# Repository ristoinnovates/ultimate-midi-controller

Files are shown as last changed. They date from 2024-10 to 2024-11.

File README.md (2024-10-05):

# Ultimate MIDI Controller

Ultimate MIDI Controller

## Overview

The Ultimate MIDI Controller is designed to function as both a MIDI keyboard and an effects controller. Whether you're a music producer or live performer, this controller provides seamless control over MIDI devices and software.

🎬 **Watch the build process on YouTube: [Ultimate MIDI Controller Build](https://www.youtube.com/watch?v=xiZ_aWyoJGo)**

## Features

- **8 Programmable Pushbuttons**: Fully customizable to control your MIDI software or devices.
- **2 Sliding Potentiometers (10K)**: Smooth control for faders or other continuous parameters.
- **2 Rotary Potentiometers (10K)**: Perfect for volume, effects, or other rotary controls.
- **1 Rotary Encoder with Button**: Precision control for effects, menus, or settings.
- **1 Joystick**: Adds dynamic control, ideal for pitch bending, modulation, or any custom input.
- **30 Mechanical Key Switches**: Custom tactile and clicky switches with keycaps, offering a responsive feel.
- **Tiny Neodymium Magnets**: Secure and modular connections for various components.
- **Display (SPI Protocol)**: Provides real-time feedback on settings, effects, or controls.
- **Custom 3D Printed Enclosure**: Designed from scratch, this custom top and bottom enclosure houses all components securely.
- **Powered by Arduino Pro Micro**: The heart of the controller, driving all the components with powerful control.

## Components

- **Potentiometers**: 10K ohm (linear)
- **Switches**: Clicky mechanical switches with keycaps
- **Display**: SPI-connected display
- **3D Printed Enclosure**: Custom-designed for a sleek, modular build

For a full list of components and assembly details, visit: [Ultimate MIDI Controller on RistoInnovates.com](https://ristoinnovates.com/product/ultimate-midi-controller/)

## Downloads

- **Enclosure STL Files**: Download the 3D-printable files for the top and bottom enclosure.
- **Schematics & Code**: Download the wiring schematics and Arduino code.

> **Note:** The code is actively being developed. If you find any missing features or bugs, check back later for updates.

## How to Build

1. Print the enclosure using the provided STL files.
2. Assemble the components as per the schematics.
3. Upload the provided Arduino code to your Pro Micro.
4. Enjoy your new customizable MIDI controller!

## Contributions

Feel free to submit pull requests or open issues if you have any ideas or improvements!

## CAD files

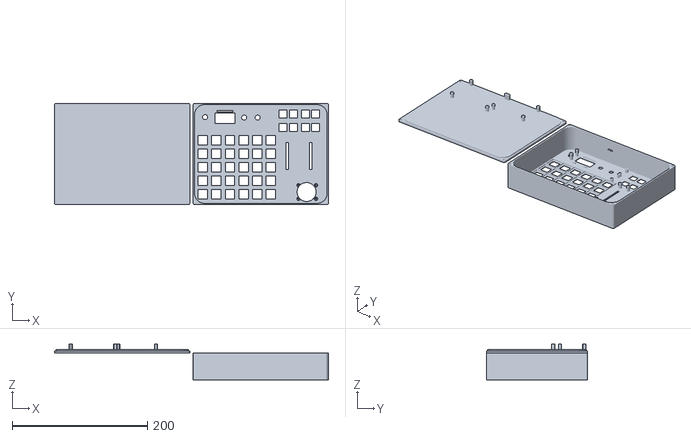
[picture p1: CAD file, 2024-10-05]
Ultimate Midi Controller.stl
405.0 x 150.0 x 53.0

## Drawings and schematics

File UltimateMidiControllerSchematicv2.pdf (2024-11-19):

1 | 2 U1.25
1 | 2 U1.25

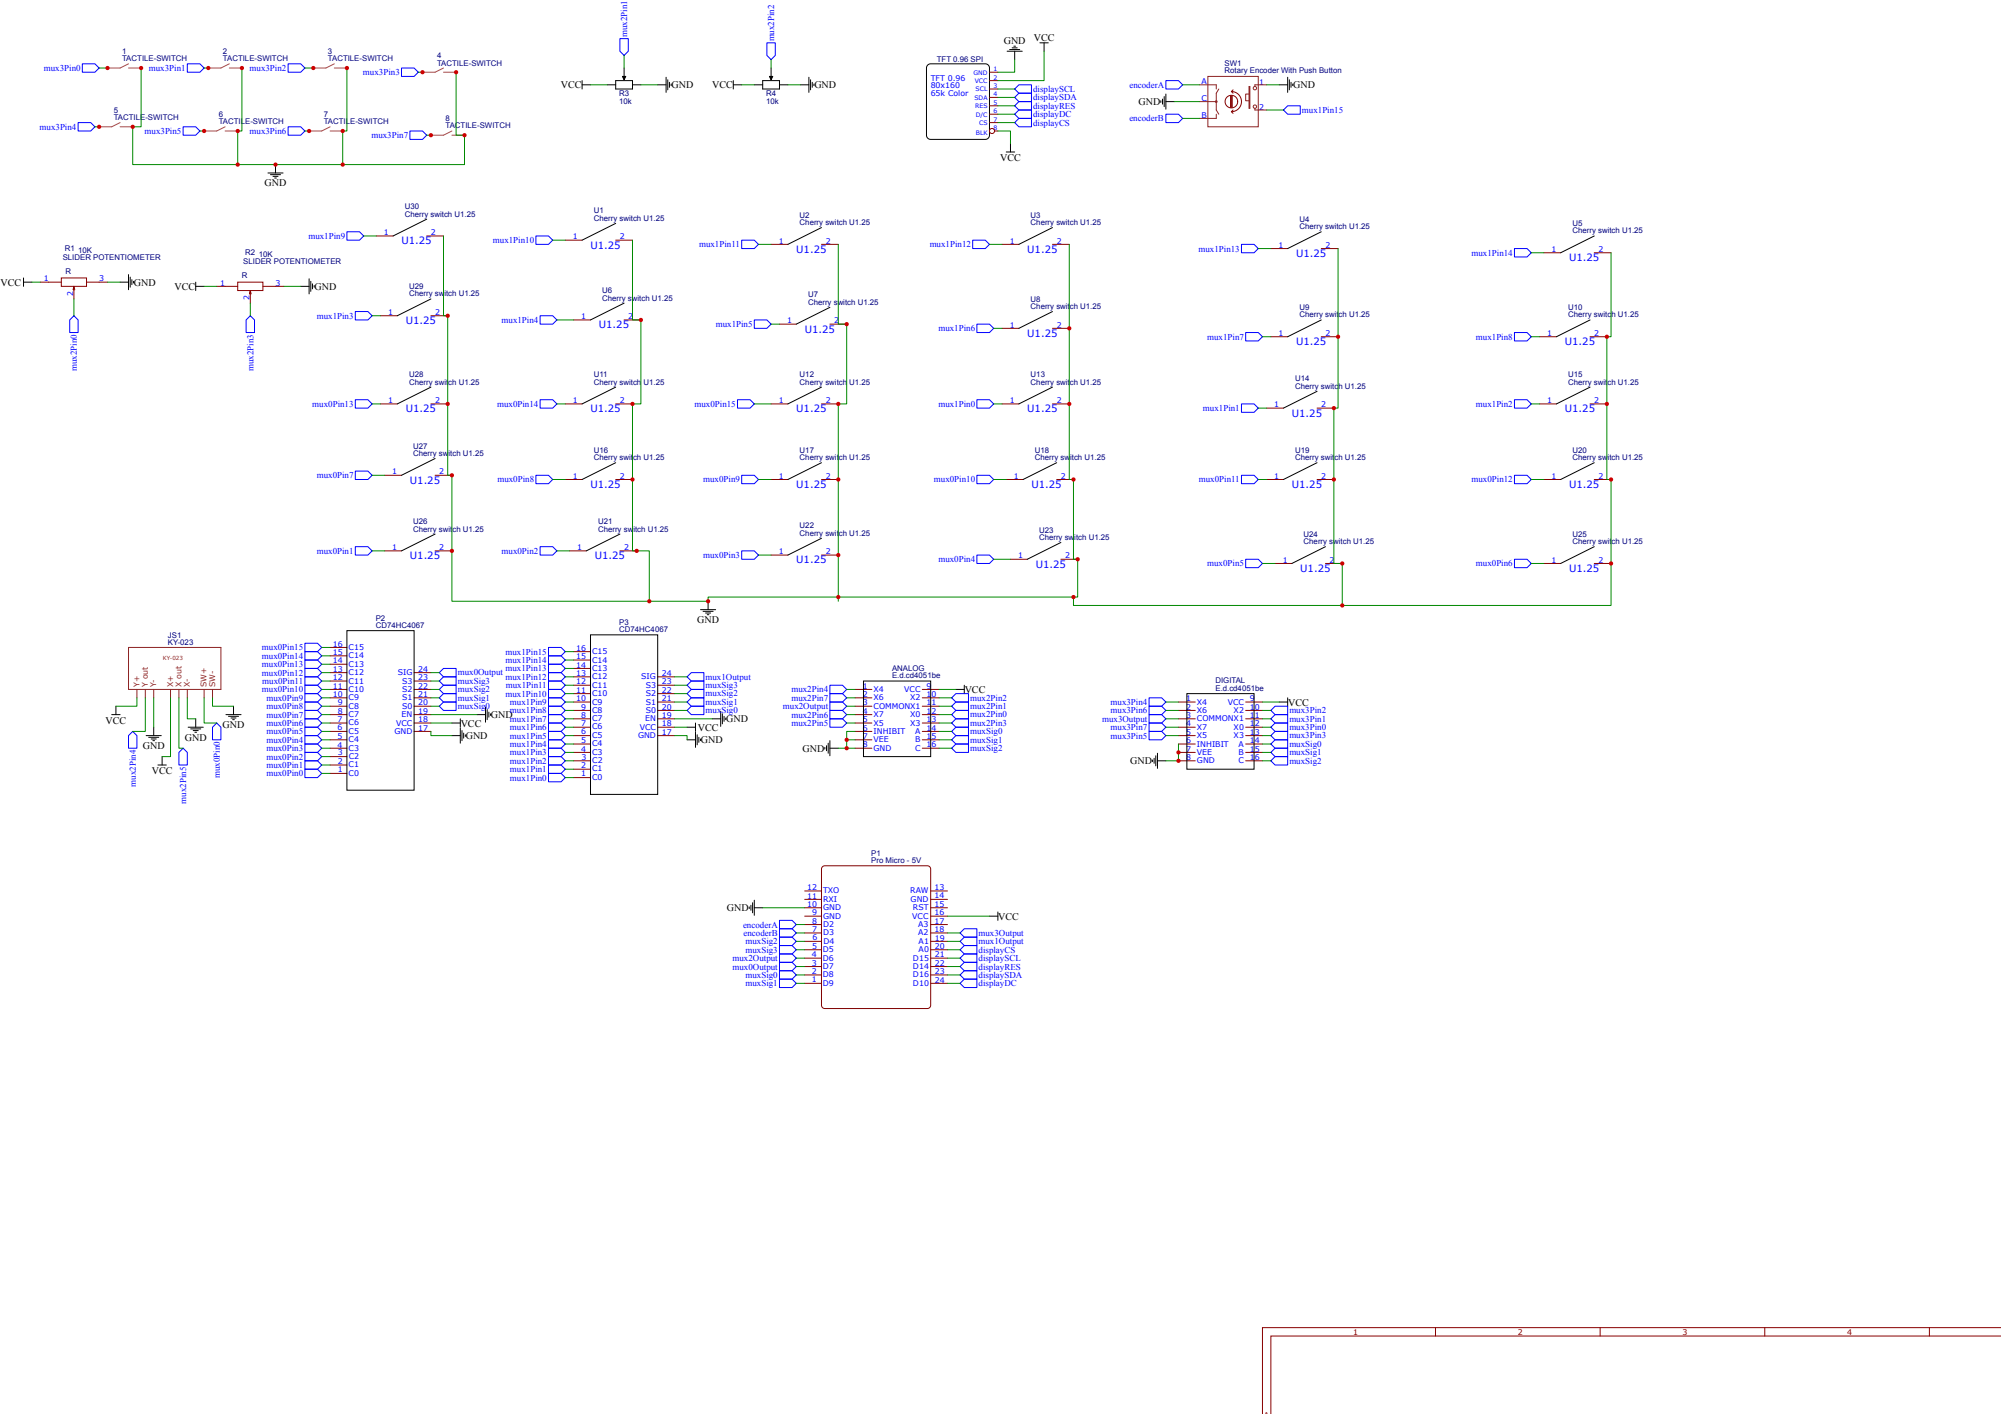
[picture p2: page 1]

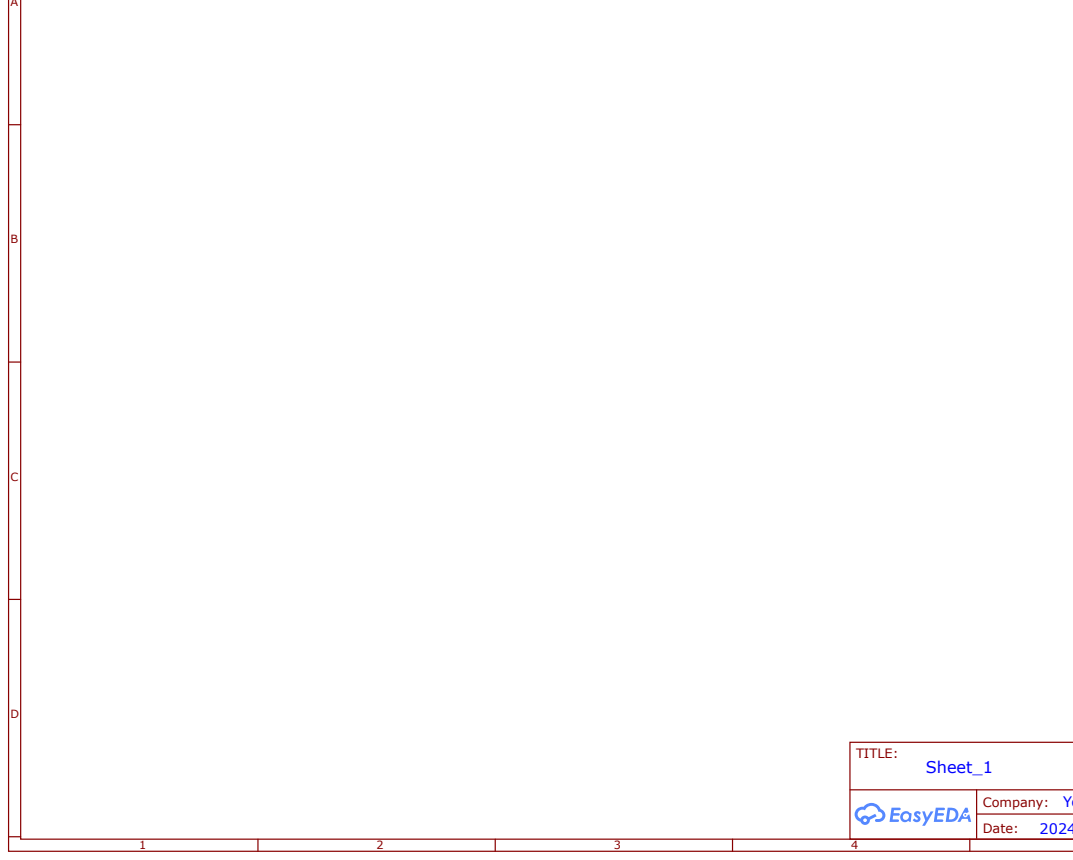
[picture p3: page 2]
TITLE:; Sheet_1; Date:; Company: Yo

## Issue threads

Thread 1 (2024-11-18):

mux2pin15

ragekillen, 2024-11-18:
Is the rotary encoder with button supposed to be mux1pin15 or is it supposed to go to pin 15 on the cd4051be chip (muxSig1). pretty sure its just a typo in the schematic

ristoinnovates, 2024-11-18:
You are correct! Good catch! It's supposed to be mux1Pin15.

I counted the 4067s as one and two, and the 4051s as one and two as well when making the schematic.

Thank you for checking it. I'll update it when I get a chance! Send me an email at ristoinnovates@gmail.com, I'll send you a 15% OFF coupon code if you ever want to get a device from my website.

Thanks!

ragekillen, 2024-11-18:
thanks for confirming that. As for the coupon i appreciate the offer but no need i would rather support you by paying the full amount

Closed 2024-11-18.

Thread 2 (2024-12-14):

couple questions / issues

ragekillen, 2024-12-14:
1. 7 keys are out of order in FL Studio is there any way to realign them in the code (serial output says there in the correct order)
2. is there any use to the FX Ctrl / mixer section at this time or is it just kind of there for now

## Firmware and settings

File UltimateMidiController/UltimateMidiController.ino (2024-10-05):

#include <Arduino.h>
#include "MIDIUSB.h"
#include <Encoder.h>
#include "Keyboard.h"
// Display Libraries
#include <Adafruit_GFX.h>    // Core graphics library
#include <Adafruit_ST7735.h> // Hardware-specific library for ST7735
#include <SPI.h>

// For the Adafruit 0.96" TFT with ST7735
#define TFT_CS     18  // Chip select line for TFT (can be any digital pin)
#define TFT_RST    14  // Reset line for TFT (or connect to Arduino RESET pin)
#define TFT_DC     10  // Data/command line for TFT (can be any digital pin)
#define TFT_MOSI   16  // Data out (MOSI) pin for SPI
#define TFT_SCLK   15  // Clock out (SCLK) pin for SPI

Adafruit_ST7735 tft = Adafruit_ST7735(TFT_CS, TFT_DC, TFT_RST);


// PINOUT
// MUX
// Outputs
int muxChannel1 = 8;
int muxChannel2 = 9;
int muxChannel3 = 4;
int muxChannel4 = 5;

// Inputs
int muxPotsInput = A7; // 8 channel analog
int muxSwitchesInput1 = 7; // 16 channel digital
int muxSwitchesInput2 = 19; // 16 channel digital
int muxPushButtonsInput = 20; // 8 channel digital


// # MULTIPLEXER 1 BUTTONS - 8 CH

const int NUMBER_MUX_1_BUTTONS = 8;
bool muxButtons1CurrentState[NUMBER_MUX_1_BUTTONS] = {0};
bool muxButtons1PreviousState[NUMBER_MUX_1_BUTTONS] = {0};

unsigned long lastDebounceTimeMUX1[NUMBER_MUX_1_BUTTONS] = {0};
unsigned long debounceDelayMUX1 = 5;

// # -------------------

// # MULTIPLEXER 2 BUTTONS - 16 CH

const int NUMBER_MUX_2_BUTTONS = 16;
bool muxButtons2CurrentState[NUMBER_MUX_2_BUTTONS] = {0};
bool muxButtons2PreviousState[NUMBER_MUX_2_BUTTONS] = {0};

unsigned long lastDebounceTimeMUX2[NUMBER_MUX_2_BUTTONS] = {0};
unsigned long debounceDelayMUX2 = 5;

// # -------------------

// # MULTIPLEXER 3 BUTTONS - 16 CH

const int NUMBER_MUX_3_BUTTONS = 16;
bool muxButtons3CurrentState[NUMBER_MUX_3_BUTTONS] = {0};
bool muxButtons3PreviousState[NUMBER_MUX_3_BUTTONS] = {0};

unsigned long lastDebounceTimeMUX3[NUMBER_MUX_3_BUTTONS] = {0};
unsigned long debounceDelayMUX3 = 5;

// # -------------------


// # MULTIPLEXER 4 POTS - 8 CH

const int NUMBER_MUX_4_POTS = 6;
int muxPots4CurrentState[NUMBER_MUX_4_POTS] = {0};
int muxPots4PreviousState[NUMBER_MUX_4_POTS] = {0};
int muxPots4PreviousMidiState[NUMBER_MUX_4_POTS] = {0}; // To store previous MIDI states

unsigned long lastDebounceTimeMUX4[NUMBER_MUX_4_POTS] = {0};
const unsigned long debounceDelayMUX4 = 5;
const int varThreshold = 10;

// # -------------------

// Encoder
// switching the encoder from 19 and 20 to 8 and 9, and switching the muxSwitchesInput2 and muxPushButtonsInput form 8 and 9 to 19 and 20
int encoderPinA = 2;
int encoderPinB = 3;

Encoder myEncoder(encoderPinA, encoderPinB); // Use the Encoder library for easy handling
int oldEncoderPos = 0; // To track changes in encoder position






int selectedChannel = 0;
int octave = 0;
int notesOctave = 0;


// Define menu items
const int totalMenuItems = 3;
String menuItems[totalMenuItems] = {"INSTRUMENT", "FX CTRL", "MIXER"};
int currentMenuIndex = 0;
bool inMenu = false;

void setup() {
  // Initialize serial communication for debugging (optional)
  Serial.begin(9600);

  // Configure multiplexer output pins
  pinMode(muxChannel1, OUTPUT);
  pinMode(muxChannel2, OUTPUT);
  pinMode(muxChannel3, OUTPUT);
  pinMode(muxChannel4, OUTPUT);
  digitalWrite(muxChannel1, LOW);
  digitalWrite(muxChannel2, LOW);
  digitalWrite(muxChannel3, LOW);
  digitalWrite(muxChannel4, LOW);

  // Set up multiplexer input pins
  pinMode(muxPotsInput, INPUT); // Analog input for potentiometers
  pinMode(muxSwitchesInput1, INPUT_PULLUP); // Digital input for the first set of switches
  pinMode(muxSwitchesInput2, INPUT_PULLUP); // Digital input for the second set of switches
  pinMode(muxPushButtonsInput, INPUT_PULLUP); // Digital input for push buttons
  //
  pinMode(encoderPinA, INPUT_PULLUP);
  pinMode(encoderPinB, INPUT_PULLUP);

  // Initialize the display
  tft.initR(INITR_GREENTAB);

  tft.setRotation(-1);
  tft.invertDisplay(1);
  tft.fillScreen(ST7735_BLACK);

  tft.setTextColor(ST7735_ORANGE);
  tft.setTextSize(2);
  tft.setCursor(22, 20);
  tft.println("Risto");
  tft.setCursor(20, 40);
  tft.println("Innovates");

  // Print setup completion message
  Serial.println("Setup complete.");
  delay(2000);
  updateDisplay(oldEncoderPos, currentMenuIndex);  // Initial display update

}

void loop() {

  updateEncoder();
  updateMUX1PushButtons();
  updateMUX2Buttons();
  updateMUX3Buttons();
  updateMUX4Pots();

  //    delay(50); // Reduce output speed
}

void updateMUX1PushButtons() {
  for (int i = 0; i <  NUMBER_MUX_1_BUTTONS; i++) {
    //// Select channel of the multiplexer
    int A = bitRead(i, 0); //Take first bit from binary value of i channel.
    int B = bitRead(i, 1); //Take second bit from binary value of i channel.
    int C = bitRead(i, 2); //Take third bit from value of i channel.
    digitalWrite(muxChannel1, A);
    digitalWrite(muxChannel2, B);
    digitalWrite(muxChannel3, C);
    delay(1);
    
    muxButtons1CurrentState[i] = digitalRead(muxPushButtonsInput);

    if ((millis() - lastDebounceTimeMUX1[i]) > debounceDelayMUX1) {
      if (muxButtons1CurrentState[i] != muxButtons1PreviousState[i]) {
        lastDebounceTimeMUX1[i] = millis();

        if (muxButtons1CurrentState[i] == LOW) {
          pressButton(1, i, 0);
          Serial.print("Mux 1 Button: ");
          Serial.println(i);
        } else {
          pressButton(1, i, 1);
        }

        muxButtons1PreviousState[i] = muxButtons1CurrentState[i];
      }
    }
  }
}

void updateMUX2Buttons() {
  for (int i = 0; i <  NUMBER_MUX_2_BUTTONS; i++) {
    //// Select channel of the multiplexer
    int A = bitRead(i, 0); //Take first bit from binary value of i channel.
    int B = bitRead(i, 1); //Take second bit from binary value of i channel.
    int C = bitRead(i, 2); //Take third bit from value of i channel.
    int D = bitRead(i, 3); //Take third bit from value of i channel.
    digitalWrite(muxChannel1, A);
    digitalWrite(muxChannel2, B);
    digitalWrite(muxChannel3, C);
    digitalWrite(muxChannel4, D);
    delay(1);
    muxButtons2CurrentState[i] = digitalRead(muxSwitchesInput1);

    if ((millis() - lastDebounceTimeMUX2[i]) > debounceDelayMUX2) {
      if (muxButtons2CurrentState[i] != muxButtons2PreviousState[i]) {
        lastDebounceTimeMUX2[i] = millis();

        if (muxButtons2CurrentState[i] == LOW) {
          pressButton(2, i, 0);
          Serial.print("Mux 2 Button: ");
          Serial.println(i);
        } else {
          pressButton(2, i, 1);
        }

        muxButtons2PreviousState[i] = muxButtons2CurrentState[i];
      }
    }
  }
}

void updateMUX3Buttons() {
  for (int i = 0; i <  NUMBER_MUX_3_BUTTONS; i++) {
    //// Select channel of the multiplexer
    int A = bitRead(i, 0); //Take first bit from binary value of i channel.
    int B = bitRead(i, 1); //Take second bit from binary value of i channel.
    int C = bitRead(i, 2); //Take third bit from value of i channel.
    int D = bitRead(i, 3); //Take third bit from value of i channel.
    digitalWrite(muxChannel1, A);
    digitalWrite(muxChannel2, B);
    digitalWrite(muxChannel3, C);
    digitalWrite(muxChannel4, D);
    delay(1);
    muxButtons3CurrentState[i] = digitalRead(muxSwitchesInput2);

    if ((millis() - lastDebounceTimeMUX3[i]) > debounceDelayMUX3) {
      if (muxButtons3CurrentState[i] != muxButtons3PreviousState[i]) {
        lastDebounceTimeMUX3[i] = millis();

        if (muxButtons3CurrentState[i] == LOW) {
          pressButton(3, i, 0);
          Serial.print("Mux 3 Button: ");
          Serial.println(i);
        } else {
          pressButton(3, i, 1);
        }

        muxButtons3PreviousState[i] = muxButtons3CurrentState[i];
      }
    }
  }
}

void updateMUX4Pots() {
  for (int i = 0; i < NUMBER_MUX_4_POTS; i++) {
    digitalWrite(muxChannel1, bitRead(i, 0));
    digitalWrite(muxChannel2, bitRead(i, 1));
    digitalWrite(muxChannel3, bitRead(i, 2));
    delay(1);  // Minimize this delay if response is too slow

    int potValue = analogRead(muxPotsInput);
    int midiValue = map(potValue, 0, 1023, 127, 0);
    if (i == 1 || i == 2) {
      midiValue = map(potValue, 0, 1023, 0, 127);
    } 
    

    if (i == 4) {  // Assuming channel 4 is for modulation
      midiValue = map(potValue, 0, 1023, 127, 0);
      int correctedValueMod = potValue - 511;  // Adjusted to your actual midpoint
      midiValue = map(correctedValueMod, -511, 512, 127, 0);
      
    } else if (i == 5) {  // Assuming channel 5 is for pitch bend
      int correctedValuePitch = potValue - 511;  // Adjusted to your actual midpoint
      midiValue = map(correctedValuePitch, -512, 512, -8192, 8191);
    }

    if (abs(potValue - muxPots4PreviousState[i]) > varThreshold) {
      unsigned long currentTime = millis();
      if ((currentTime - lastDebounceTimeMUX4[i]) > debounceDelayMUX4) {
        lastDebounceTimeMUX4[i] = currentTime;

        if (midiValue != muxPots4PreviousMidiState[i]) {
          Serial.print("Pot ");
          Serial.print(i);
          Serial.print(": ");
          Serial.println(midiValue);
          switch (i){
            case 0:
              // left slider
              midiControlChange(selectedChannel, 80, midiValue);
              break;
            case 1:
              // left pot
              midiControlChange(selectedChannel, 82, midiValue);
              break;
            case 2:
              // right pot
              midiControlChange(selectedChannel, 83, midiValue);
              break;
            case 3:
              // right slider
              midiControlChange(selectedChannel, 81, midiValue);
              break;
            case 4:
              // Modulation
              midiControlChange(selectedChannel, 1, midiValue);
              break;
            case 5:
              // Pitch Bend
              midiPitchBend(selectedChannel, midiValue + 8192);  // Normalize the pitch
              break;
          }

          muxPots4PreviousState[i] = potValue;
          muxPots4PreviousMidiState[i] = midiValue;
        }
      }
    }
  }
}

void updateEncoder() {
  int newEncoderPos = myEncoder.read() / 2; // Read the current encoder position
  if (newEncoderPos != oldEncoderPos) {
//    Serial.print("Old Pos: ");
//    Serial.print(oldEncoderPos);
//    Serial.print(" New Pos: ");
//    Serial.println(newEncoderPos);

    // Calculate direction of rotation
    int direction = (newEncoderPos > oldEncoderPos) ? 1 : -1;
    if (!inMenu){
      currentMenuIndex += direction;

      // Wrap around the menu index
      if (currentMenuIndex >= totalMenuItems) currentMenuIndex = 0;
      else if (currentMenuIndex < 0) currentMenuIndex = totalMenuItems - 1;
  
        updateDisplay(oldEncoderPos, currentMenuIndex);  
      } else {
        if (currentMenuIndex == 0){
          if (direction == -1) {
            Keyboard.press(91);
            Keyboard.release(91);
          } else {
            Keyboard.press(93);
            Keyboard.release(93);
          }
        }
      }
    
    oldEncoderPos = newEncoderPos; // Update the last known position
  }
}

void updateDisplay(int oldIndex, int newIndex) {
  Serial.print("Updating display from ");
  Serial.print(oldIndex);
  Serial.print(" to ");
  Serial.println(newIndex);

  if (inMenu){
    switch (newIndex) {
      case 0:
        tft.fillScreen(ST7735_BLACK);  // Clear screen before updating new values
        tft.setTextColor(ST7735_ORANGE, ST7735_BLACK);
        tft.setTextSize(2);
        tft.setCursor(5, 0);
        tft.println("< INSTRUMENT");
        tft.setTextColor(ST7735_BLUE, ST7735_BLACK);
        tft.setTextSize(1);
        tft.setCursor(5, 20);
        tft.print("Octave: ");
        tft.print(octave);
        tft.print("  Transpose: ");
        tft.println(notesOctave);
        tft.setCursor(5, 20 + 40);
        tft.println("test 3");
        break;
      case 1:
        tft.fillScreen(ST7735_BLACK);  // Clear screen before updating new values
        tft.setTextColor(ST7735_ORANGE, ST7735_BLACK);
        tft.setTextSize(2);
        tft.setCursor(5, 0);
        tft.println("< FX CTRL");
        tft.setTextColor(ST7735_BLUE, ST7735_BLACK);
        tft.setCursor(5, 20);
        tft.println("test 4");
        tft.setCursor(5, 20 + 20);
        tft.println("test 5");
        tft.setCursor(5, 20 + 40);
        tft.println("test 6");
        break;
      case 2:
        tft.fillScreen(ST7735_BLACK);  // Clear screen before updating new values
        tft.setTextColor(ST7735_ORANGE, ST7735_BLACK);
        tft.setTextSize(2);
        tft.setCursor(5, 0);
        tft.println("< MIXER");
        tft.setTextColor(ST7735_BLUE, ST7735_BLACK);
        tft.setCursor(5, 20);
        tft.println("test 7");
        tft.setCursor(5, 20 + 20);
        tft.println("test 8");
        tft.setCursor(5, 20 + 40);
        tft.println("test 9");
        break;
        break;
    }
  } else {
    tft.fillScreen(ST7735_BLACK);  // Clear screen before updating new values
    tft.setTextColor(ST7735_ORANGE, ST7735_BLACK);
    tft.setTextSize(2);
    tft.setCursor(5, 0);
    tft.println("Select MODE:");
    tft.setTextColor(ST7735_BLUE, ST7735_BLACK);
    for (int i = 0; i < totalMenuItems; i++) {
      tft.setCursor(5, 20 + i * 20);
      if (i == newIndex) {
        tft.setTextColor(ST7735_GREEN, ST7735_BLACK);
        tft.print("* ");
        tft.println(menuItems[i]);
      } else {
        tft.setTextColor(ST7735_BLUE, ST7735_BLACK);
        tft.print("  ");
        tft.println(menuItems[i]);
      }
    }
  }

  
}

void midiNoteOn(byte channel, unsigned short note) {
  midiEventPacket_t midiNoteOn = { 0x09, 0x90 | channel, note, 100 };
  MidiUSB.sendMIDI(midiNoteOn);
  MidiUSB.flush();  // Ensure the message is sent immediately
}

void midiNoteOff(byte channel, unsigned short note) {
  midiEventPacket_t midiNoteOff = { 0x08, 0x80 | channel, note, 0 };
  MidiUSB.sendMIDI(midiNoteOff);
  MidiUSB.flush();  // Ensure the message is sent immediately
}

void midiControlChange(byte channel, byte control, byte value) {
  midiEventPacket_t event = { 0x0B, 0xB0 | channel, control, value };
  MidiUSB.sendMIDI(event);
  MidiUSB.flush();  // Ensure the message is sent immediately
}

void midiPitchBend(byte channel, int bendValue) {
  // Ensure the bendValue is within the 14-bit range
  bendValue = constrain(bendValue, 0, 16383);

  // Split the 14-bit value into two 7-bit values
  byte lowByte = bendValue & 0x7F;         // Mask for the lower 7 bits
  byte highByte = (bendValue >> 7) & 0x7F; // Shift down by 7 bits and mask for the lower 7 bits

  // Form the MIDI event packet for pitch bend
  midiEventPacket_t event = {0x0E, 0xE0 | channel, lowByte, highByte};

  // Send the MIDI message
  MidiUSB.sendMIDI(event);
  MidiUSB.flush();  // Ensure the message is sent immediately
}

void pressButton(int muxNumber, int buttonNumber, int state) {
  // MUX NUMBER 
  // 1 - Push Buttons
  // 2 - Top row plus encoder button
  // 3 - Bottom row plus joystick button

  // state 0 = button Pressed
  // state 1 = button Released
  int midiNote = 36; // starting midi note
  int n; // note + current octave increase
  if (muxNumber == 1) {
    // pushbuttons
    Serial.println(buttonNumber);
    switch (buttonNumber) {
      case 0:
        if (state == 0) {
          midiControlChange(selectedChannel, 70, 127);
        } else {
          midiControlChange(selectedChannel, 70, 0);
        }
        break;
      case 1:
        // Default: Channel Solo
        // Instrument: Octave Down
        // FX CTRL: CC NUMBER
        // MIXER: CC NUMBER
        if (state == 0) {
          midiControlChange(selectedChannel, 71, 127);
        } else {
          midiControlChange(selectedChannel, 71, 0);
        }
        break;
      case 2:
        // Default: Channel Mute
        // Instrument: CC NUMBER
        // FX CTRL: CC NUMBER
        // MIXER: CC NUMBER
        if (state == 0) {
          midiControlChange(selectedChannel, 72, 127);
        } else {
          midiControlChange(selectedChannel, 72, 0);
        }
        break;
      case 3:
        if (state == 0) {
          midiControlChange(selectedChannel, 73, 127);
        } else {
          midiControlChange(selectedChannel, 73, 0);
        }
        break;
      case 4:
        // Default: Channel Record
        // Instrument: Octave Down
        // FX CTRL: CC NUMBER
        // MIXER: CC NUMBER
        
        if (state == 0) {
          if (inMenu) {
            switch (currentMenuIndex) {
              case 0: // instrument
                if (octave > -3){
                  octave--;
                }
                updateDisplay(oldEncoderPos, currentMenuIndex);  
                break;
              case 1: // fx control 
                break;
              case 2: // mixer
                break;
            }
          } else {
            midiControlChange(selectedChannel, 74, 127);  
          }
          
        } else {
          midiControlChange(selectedChannel, 74, 0);
        }
        break;
      case 5:
        // Default: Channel Input Monitor
        // Instrument: Transpose Up
        // FX CTRL: CC NUMBER
        // MIXER: CC NUMBER
        if (state == 0) {
          if (inMenu) {
            switch (currentMenuIndex) {
              case 0: // instrument
                
                notesOctave++;
                updateDisplay(oldEncoderPos, currentMenuIndex);  
                break;
              case 1: // fx control 
                break;
              case 2: // mixer
                break;
            }
          } else {
            midiControlChange(selectedChannel, 74, 127);  
          } 
        }
          else {
          midiControlChange(selectedChannel, 75, 0);
        }
        break;
      case 6:
      // Default: Channel Input Monitor
        // Instrument: Octave Up
        // FX CTRL: CC NUMBER
        // MIXER: CC NUMBER
        if (state == 0) {
          if (inMenu) {
            switch (currentMenuIndex) {
              case 0: // instrument
                if (octave < 4){
                  octave++;
                  updateDisplay(oldEncoderPos, currentMenuIndex);  
                }
                
                break;
              case 1: // fx control
                
                break;
              case 2: // mixer
                break;
            }
          } else {
            midiControlChange(selectedChannel, 74, 127);  
          }
        } else {
          midiControlChange(selectedChannel, 76, 0);
        }
        break;
      case 7:
        // Default: Channel Input Monitor
        // Instrument: Transpose Down
        // FX CTRL: CC NUMBER
        // MIXER: CC NUMBER
        if (state == 0) {
          if (inMenu) {
            switch (currentMenuIndex) {
              case 0: // instrument
                notesOctave--;
                updateDisplay(oldEncoderPos, currentMenuIndex);  
                break;
              case 1: // fx control 
                break;
              case 2: // mixer
                break;
            }
          } else {
            midiControlChange(selectedChannel, 74, 127);  
          }
        } else {
          midiControlChange(selectedChannel, 77, 0);
        }
        break;
    }
  } 
 else if (muxNumber == 2) {
  if (buttonNumber <= 7){
    n = midiNote + buttonNumber + 15 + notesOctave + 12*octave;
    if (state == 0) {
      midiNoteOn(selectedChannel, n);
    } else {
      midiNoteOff(selectedChannel, n);
    }
  } else if (buttonNumber != 15) {
    switch (buttonNumber) {
      case 8:
        n = midiNote + 12 + 15 + notesOctave + 12*octave;
        break;
      case 9:
        n = midiNote + 9 + 15 + notesOctave + 12*octave;
        break;
      case 10:
        n = midiNote + 8 + 15 + notesOctave + 12*octave;
        break;
      case 11:
        n = midiNote + 10 + 15 + notesOctave + 12*octave;
        break;
      case 12:
        n = midiNote + 14 + 15 + notesOctave + 12*octave;
        break;
      case 13:
        n = midiNote + 13 + 15 + notesOctave + 12*octave;
        break;
      case 14:
        n = midiNote + 11 + 15 + notesOctave + 12*octave;
        break;
      case 15:
        break;
    }
    if (state == 0) {
      midiNoteOn(selectedChannel, n);
    } else {
      midiNoteOff(selectedChannel, n);
    }
  } else {
    // ENCODER BUTTON
    if (state == 0) {
      if (inMenu){
        inMenu = false;
      } else {
        inMenu = true; 
      }
      updateDisplay(oldEncoderPos, currentMenuIndex);
//      midiControlChange(selectedChannel, 79, 127);
    } else {
//      midiControlChange(selectedChannel, 79, 0);
    }
  }
  
 }
  else if (muxNumber == 3) {
    if (buttonNumber == 0){
      if (state == 0) {
          midiControlChange(selectedChannel, 78, 127);
        } else {
          midiControlChange(selectedChannel, 78, 0);
        }
    } else {
      n = midiNote + buttonNumber - 1 + notesOctave + 12*octave;
      if (state == 0) {
        midiNoteOn(selectedChannel, n);
      } else {
        midiNoteOff(selectedChannel, n);
      }
    }
    
  }
}
